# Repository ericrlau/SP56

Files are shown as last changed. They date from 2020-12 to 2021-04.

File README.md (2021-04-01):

# SP56
## A ZMK-Powered BLE Keyboard, Inspired By Lily58 & Sofle

> :warning: **This is a partially tested project.** Do not use to create your own copy unless you are willing to debug the hardware and/or firmware. 
## Flash bootloader
Bootloader is pre-loaded on assembled pcbs. If you source your own BLE module you will need to unlock the module and flash the bootloader using the Nordic nrf command line tool. 
```
$ nrfjprog --recover --log 
```
```
$ nrfjprog -f nrf52 --program firmware/bootloader/COBO_nrf52840_bootloader-0.3.2-184-g64ea299_s140_6.1.1.hex
```

------------------------------------
## Upload Firmware 

- See ZMK docs for instructions on setting up ZMK and custimizing firmware.  
	* https://zmkfirmware.dev/docs/user-setup/
	* https://zmkfirmware.dev/docs/customization 
- Default *.uf2 files are pre-loaded on assembled pcbs. If you sourced and assembled your own pcb, you can file deafult pre-built firmware here: 
	- https://github.com/ericrlau/COBO-zmk-config/releases

## PCB
- Source files for pcb are in this repo. They are split into three kicad projects:
	- SP56: main pcb, left and right combined. 
	- SP56_Bottom: Bottom cover PCB. Left and right use the same part so only one copy is created. 
	- SP56_Plate: Switch plate PCB. This must be 1.2mm pcb to allow Kaihl Choc V1 switches to snap in. Left and right use the same part so only one copy is created. 
	- NOTE: KiCad files are created with nightly KiCad 5.99 builds, they are not compatible with current stable release of KiCad 5.
- Bill of materials [BOM Link](https://raw.githack.com/ericrlau/SP56/working/PCB/SP56/bom/ibom.html)
## Build Guide For PCBA
[Build Guide Link](./Build_Guide.md)

## Images

#### Prototype Build
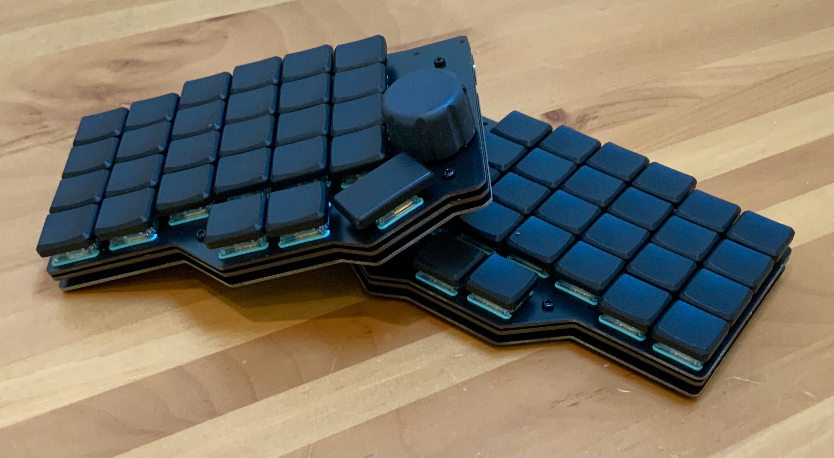
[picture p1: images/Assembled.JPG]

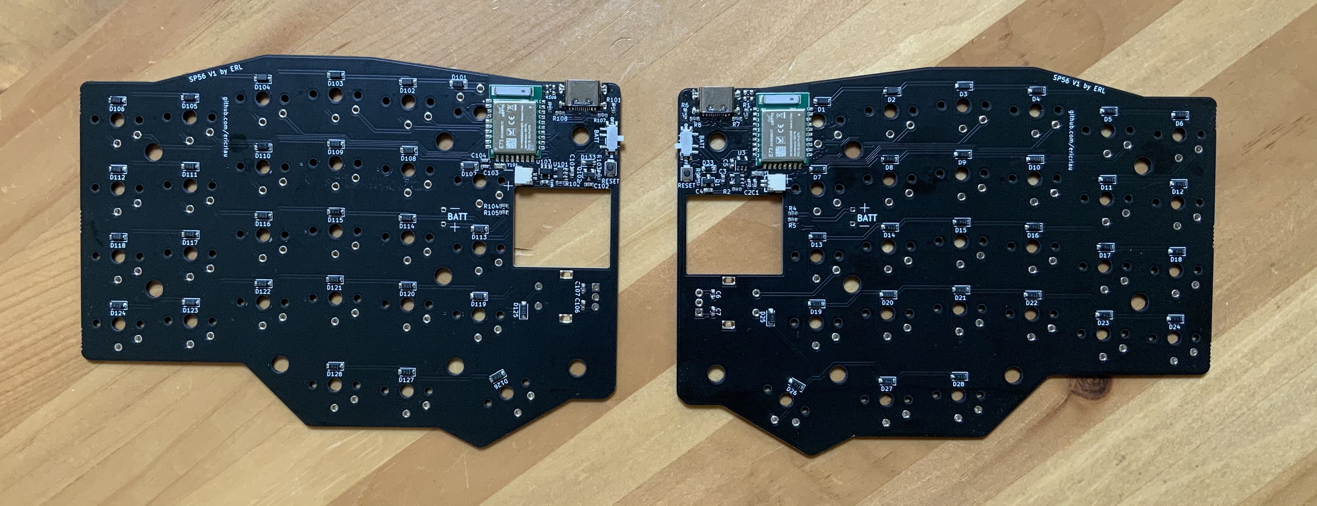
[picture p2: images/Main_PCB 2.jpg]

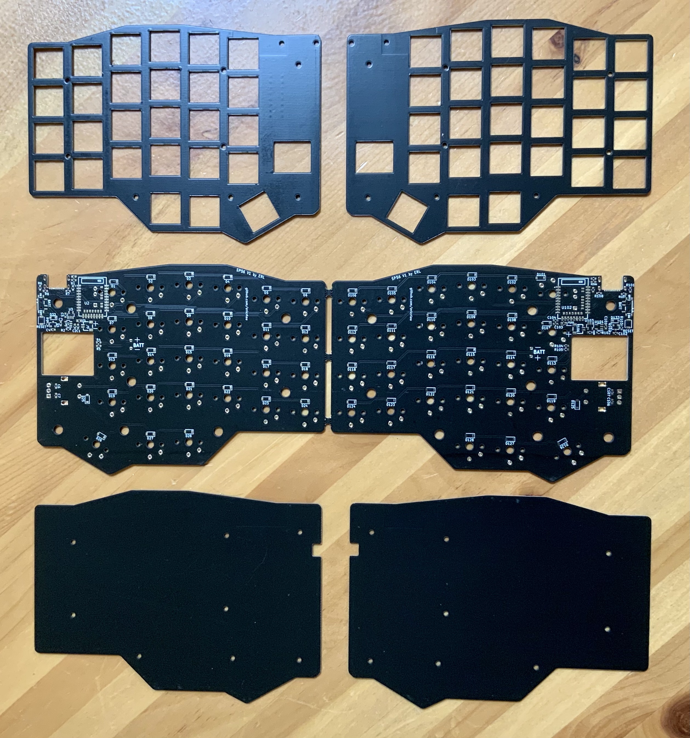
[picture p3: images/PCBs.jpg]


#### Main PCB
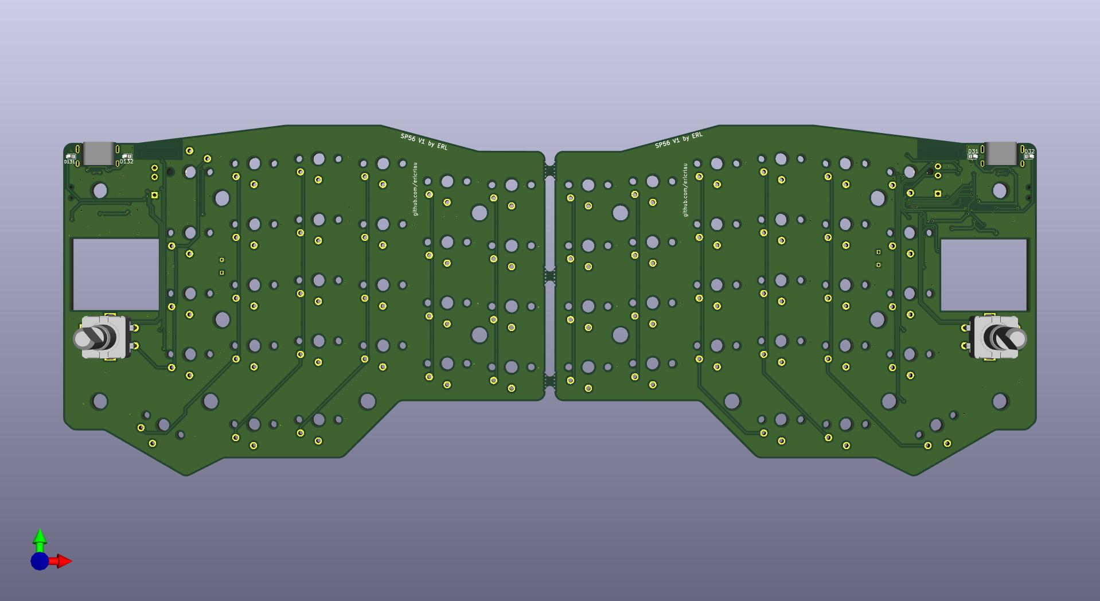
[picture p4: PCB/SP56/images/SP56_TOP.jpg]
Main TOP

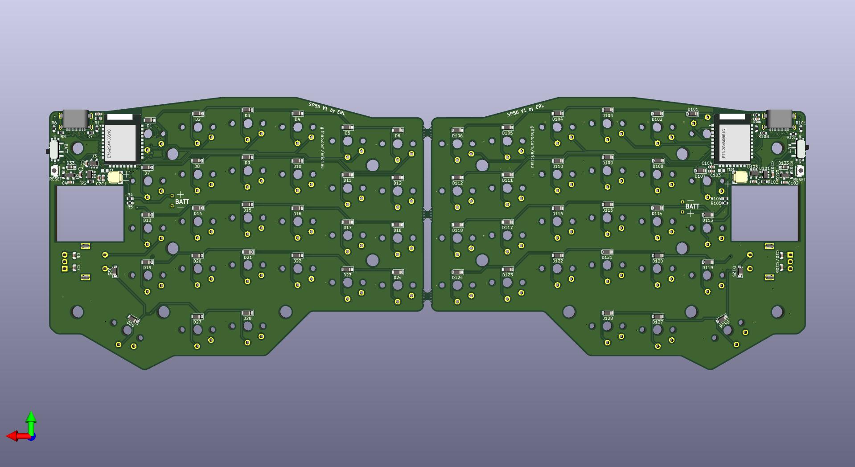
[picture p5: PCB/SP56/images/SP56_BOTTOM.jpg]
Main BOTTOM


#### FR4 Plate
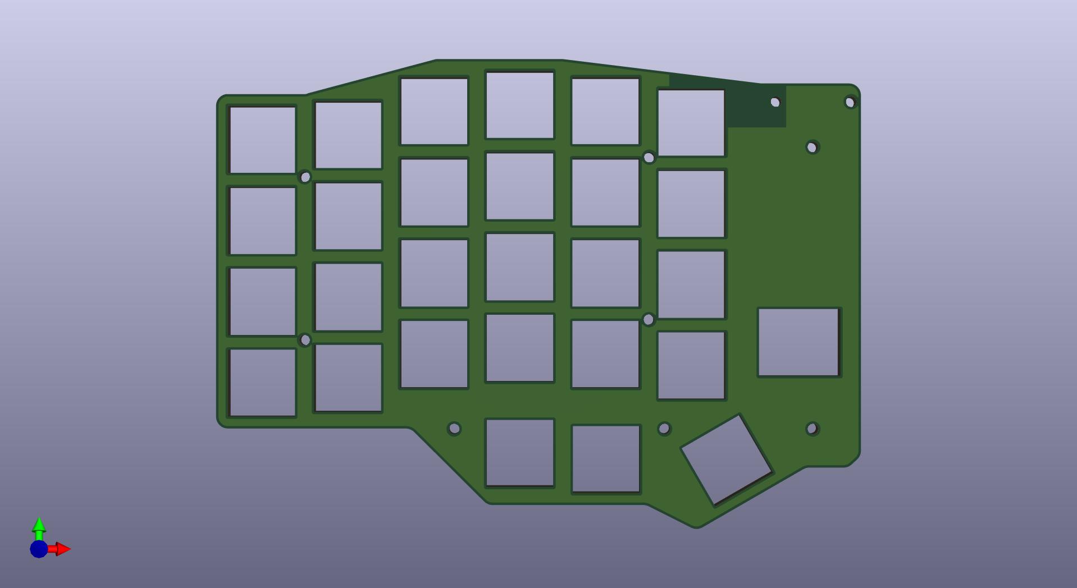
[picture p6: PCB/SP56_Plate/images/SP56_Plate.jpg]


#### Bottom PCB
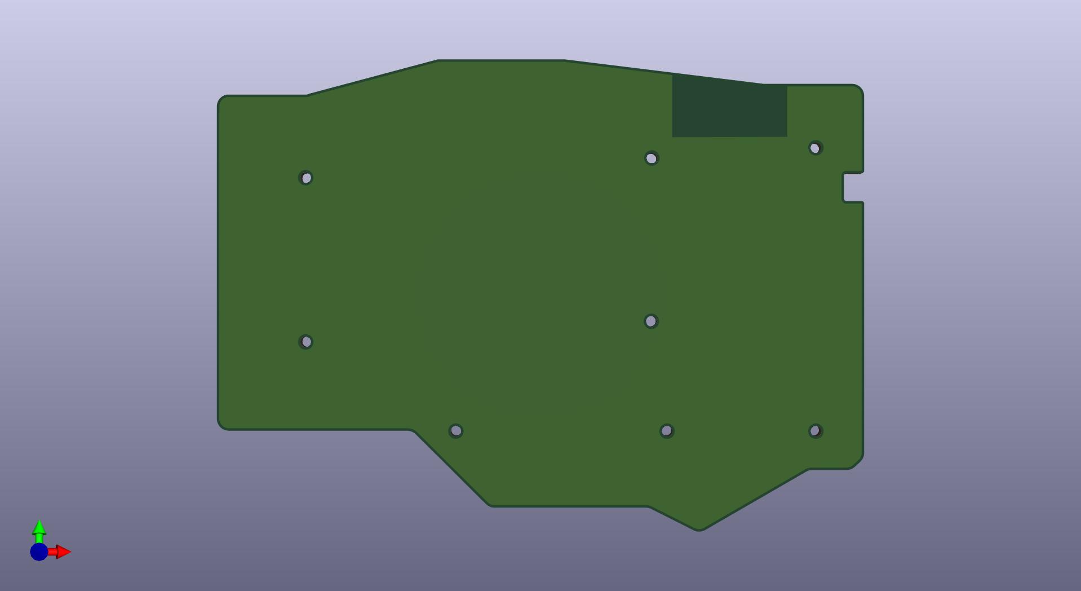
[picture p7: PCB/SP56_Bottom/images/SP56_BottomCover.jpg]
Bottom Cover


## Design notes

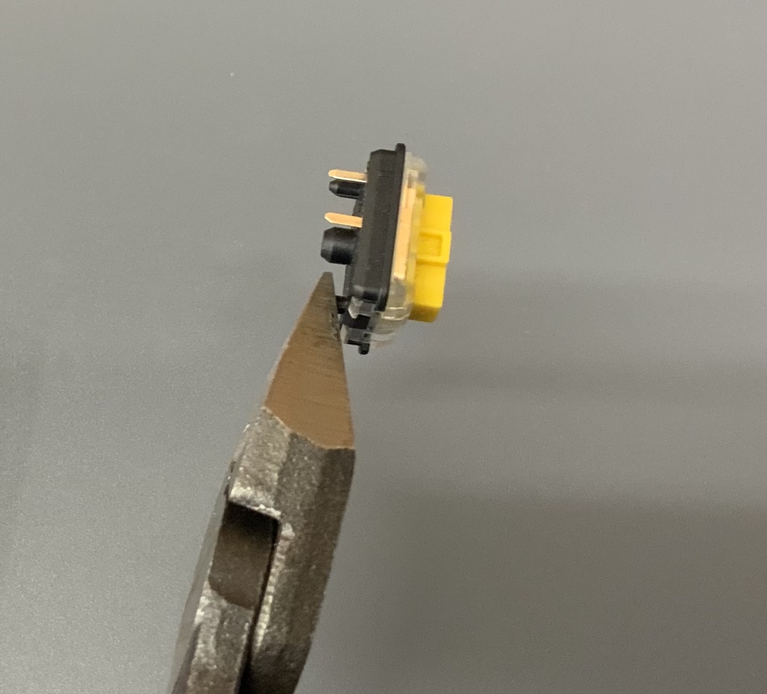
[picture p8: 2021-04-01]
images/Clip.jpg

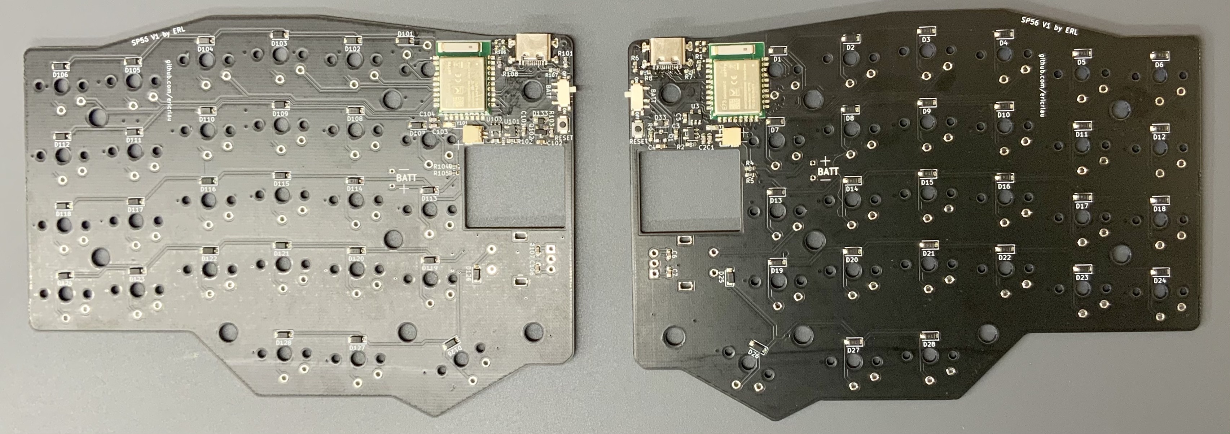
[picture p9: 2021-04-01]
images/Main_PCB.jpg

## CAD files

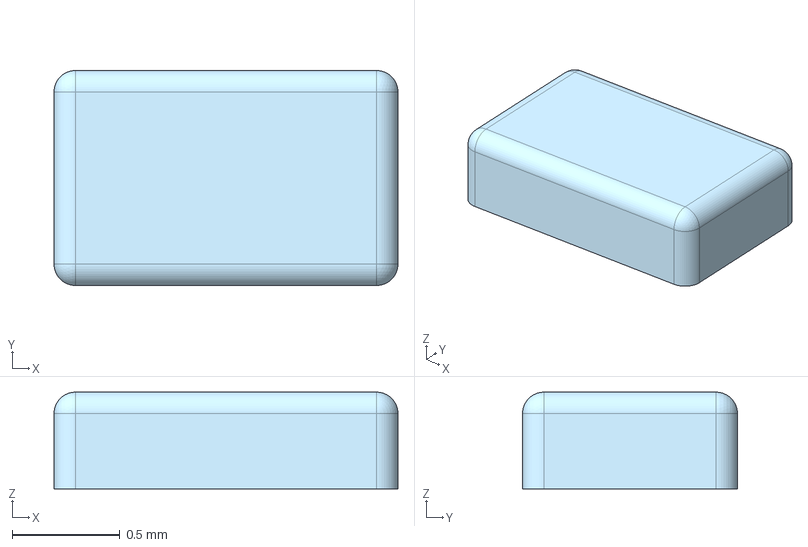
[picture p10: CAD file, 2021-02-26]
PCB/3d/DST1610A.step
1.60 x 1.00 x 0.45 mm

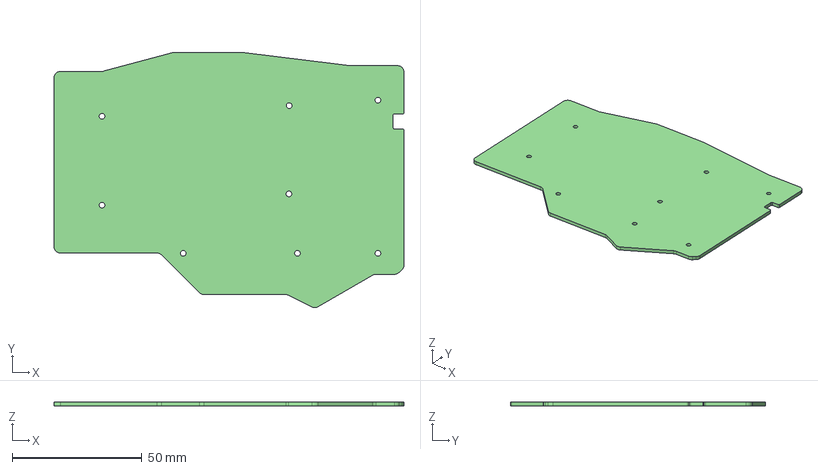
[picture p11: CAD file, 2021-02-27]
PCB/SP56_Bottom/SP56_Bottom.step
134.8 x 98.3 x 1.60 mm

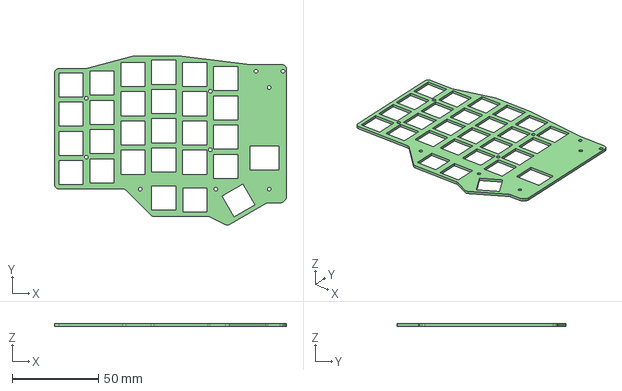
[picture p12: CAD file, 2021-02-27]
PCB/SP56_Plate/SP56_Plate.step
134.8 x 98.3 x 1.60 mm

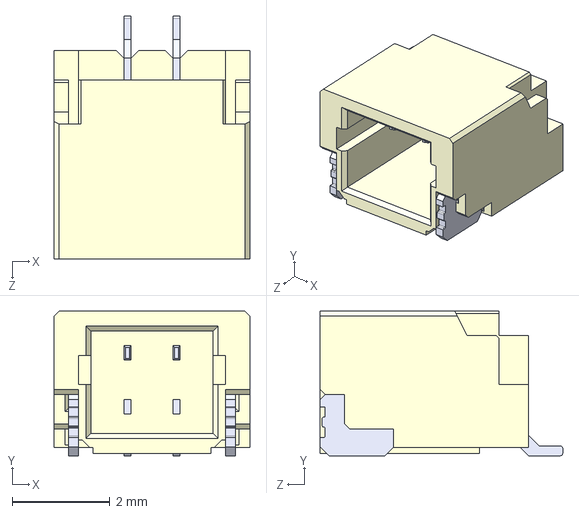
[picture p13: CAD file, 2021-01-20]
PCB/3d/SM02B-SRSS-TB_LF__SN_.step
4.00 x 2.95 x 4.95 mm

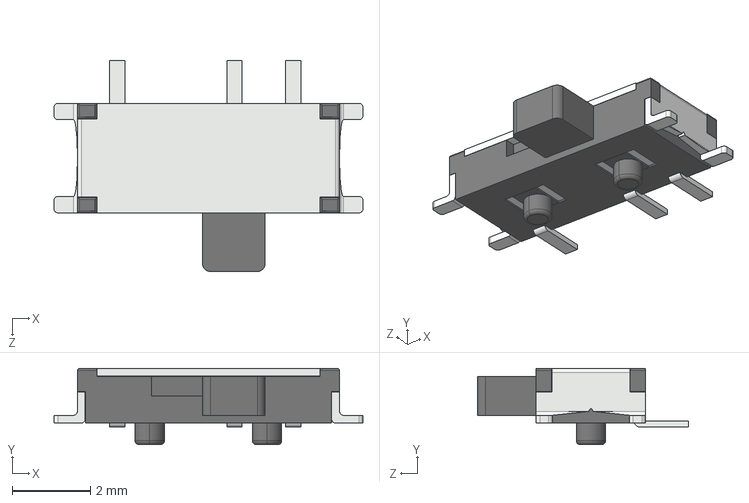
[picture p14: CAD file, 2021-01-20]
PCB/3d/MSK12C02.step
7.90 x 1.95 x 5.39 mm

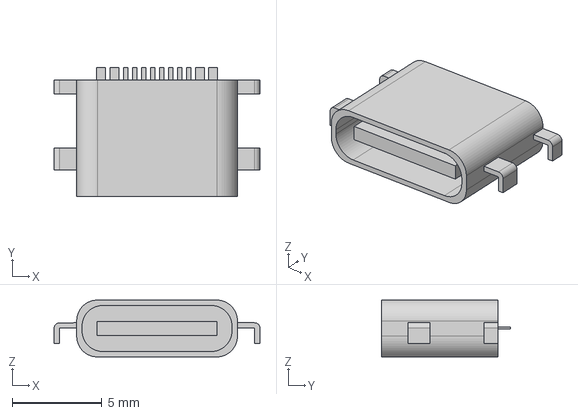
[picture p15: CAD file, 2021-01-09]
PCB/3d/USB-C-C168688.step
11.5 x 7.20 x 3.16 mm

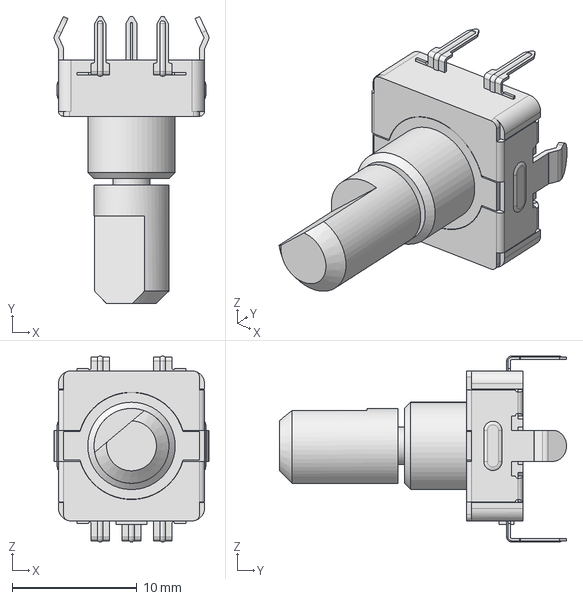
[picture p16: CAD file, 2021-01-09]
PCB/3d/EC11-THT-15F-black.step
12.4 x 23.0 x 14.9 mm

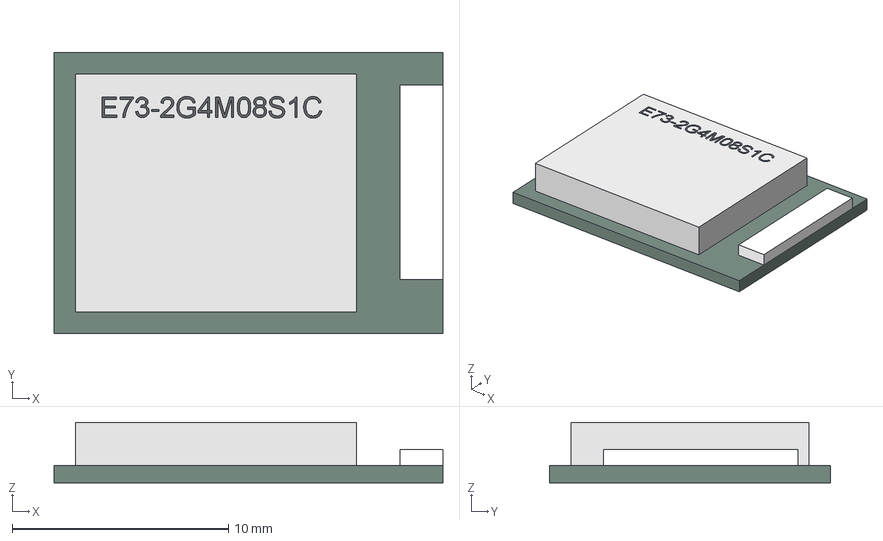
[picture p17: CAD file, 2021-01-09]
PCB/3d/E73-2G4M08S1C.step
18.0 x 13.0 x 2.81 mm

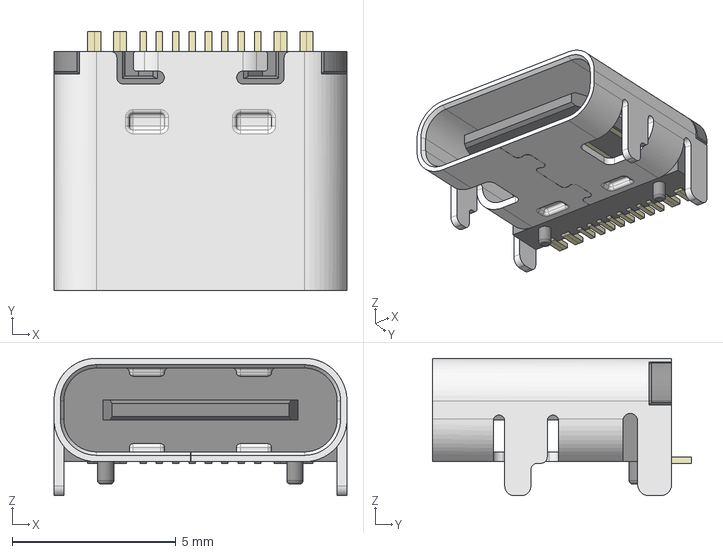
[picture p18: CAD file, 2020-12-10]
PCB/3d/HRO_TYPE-C-31-M-12.step
8.95 x 7.90 x 4.20 mm

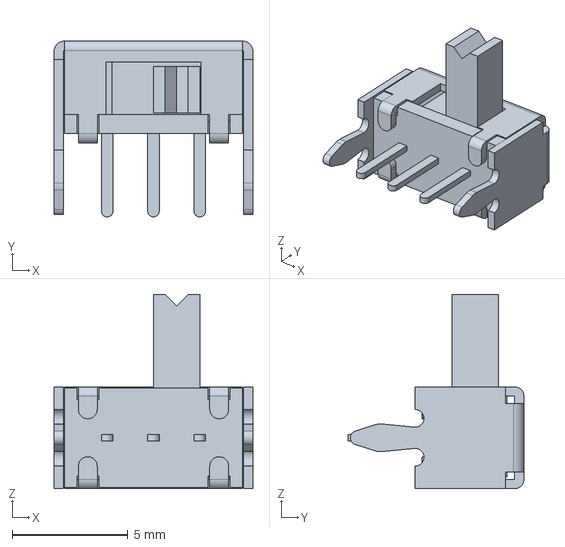
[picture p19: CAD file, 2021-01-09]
PCB/3d/OS102011MA1QN1.stp
8.60 x 7.60 x 8.40 mm

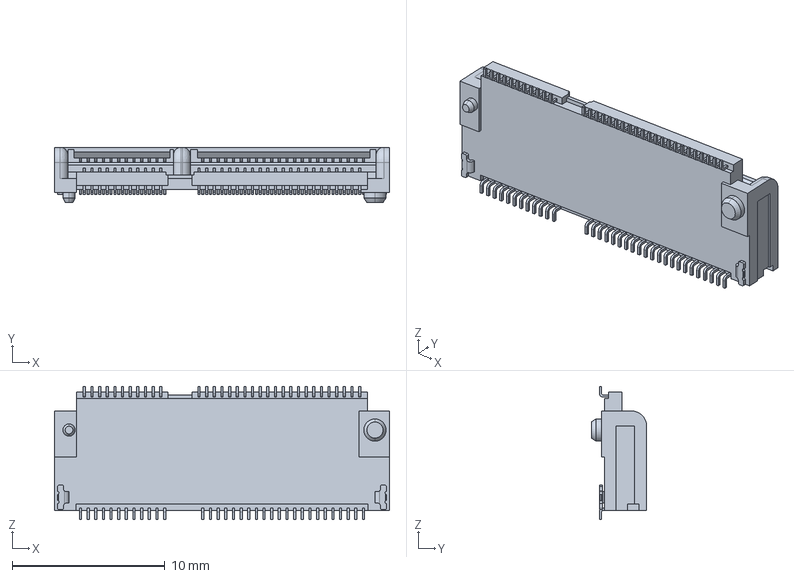
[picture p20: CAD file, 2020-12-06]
PCB/3d/2199119-4.stp
21.9 x 3.62 x 8.70 mm

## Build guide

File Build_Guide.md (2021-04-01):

# SP56
## Build Guide (From PCBA)

> :warning: **This is a partially tested project.** Do not use to create your own copy unless you are willing to debug the hardware and/or firmware. 

---
## What You'll Need
* Kaihl Choc V1 Switches - QTY 54 
* 1U Keycaps - QTY 52
* 1.5U Keycaps - QTY 2
* EC11 Encoders with Knobs - QTY 2
* Li Ion Batteries, less than 20x24x6mm - QTY 2
* Soldering Tools

---

## Unpack From Shipping
* Remove the 8 M2 screws from the top side (switch plate). 
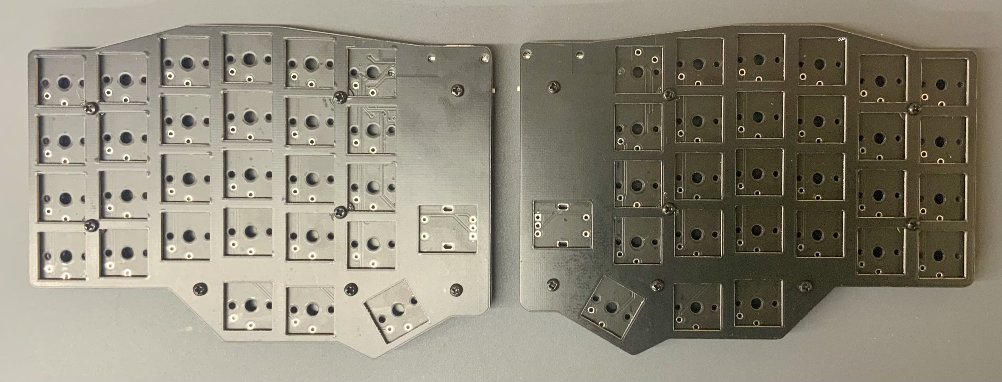
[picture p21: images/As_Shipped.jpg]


* You will see 8 1MM plastic spacers and 8 3MM thick plastic spacers, these are just for shipping and should be removed. 
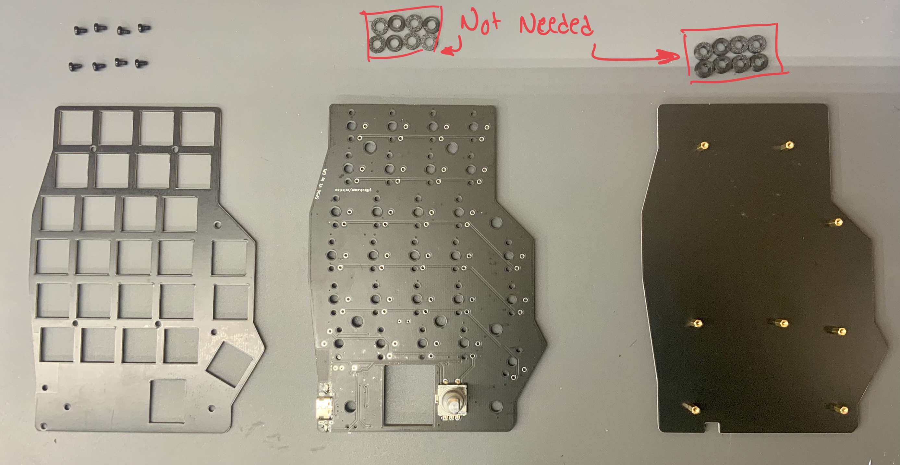
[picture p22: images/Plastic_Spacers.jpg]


## Install Encoder
The SP56 is compatible with EC11 style encoders. You will need 2 encoders and 2 knobs. Install the EC11 style encoder and solder pins. 
* NOTE: If your encoder has plastic locating nubs on the bottom these should be removed to allow encoder to sit flush. 
* Note 2: As of 31 Mar 2021, ZMK firmware does not support encoder functionality on the peripheral (right) side. The right side encoder push switch will be functional but rotating the knob will not. 
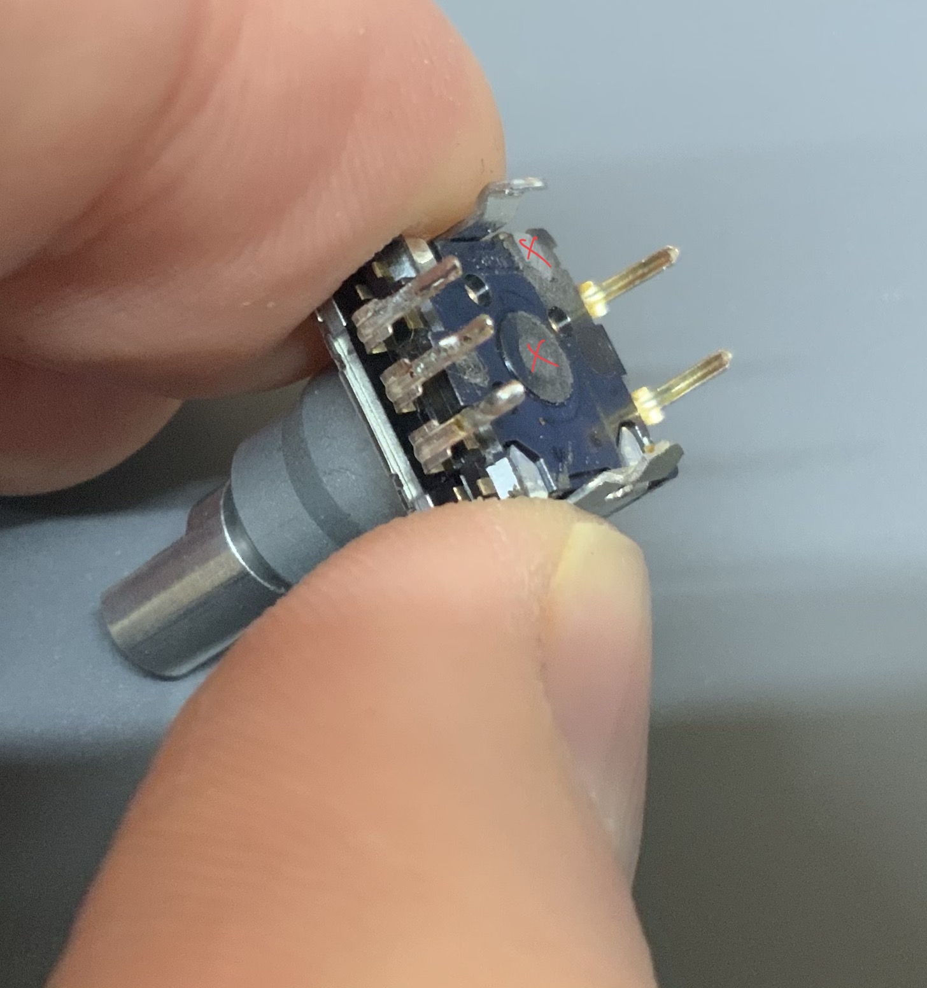
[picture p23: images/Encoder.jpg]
* 

## Plug In and Test via USB
* Before shipping any PCBAs I have flashed default firmware and checked function of all switch positions and encoders; however, it is still a good idea to plug in both PCBs to USB (left board should be connected to USB on your computer, right just needs power so you could use a usb charger) and testing again over USB since it is a lot harder to troubleshoot once the switches are soldered in. Pull up your favorite keyboard testing website and check that left encoder is working and all switch positions work if you short across the two through hole pins with a tweezers. 
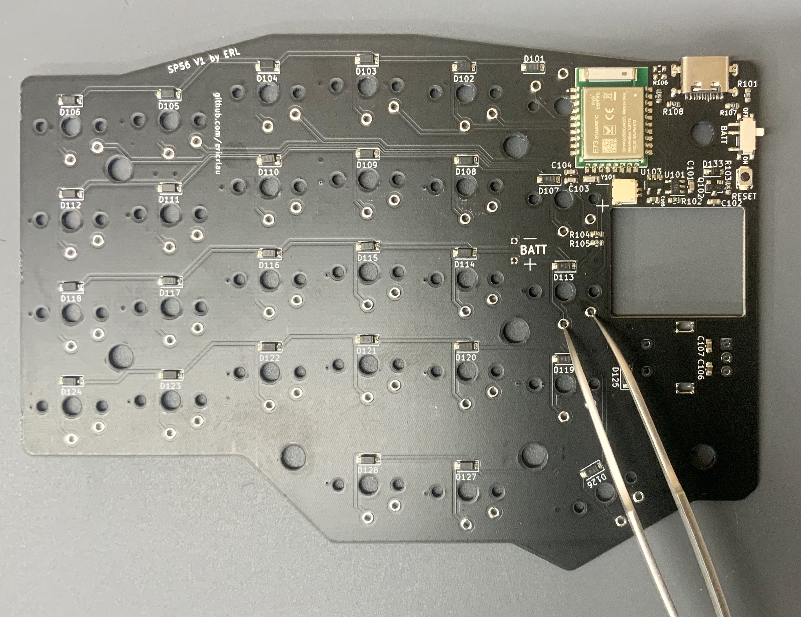
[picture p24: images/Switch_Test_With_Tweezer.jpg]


## Install Switches
The SP56 is compatible with Kaihl Choc V1 switches only. You will need 54 switches in total. 
* Trim 2 switches: On each side, the top inner switch will need to have one of the plastic legs trimmed to a length of 1.6MM or less since the wireless module is directly underneath the switch length. 
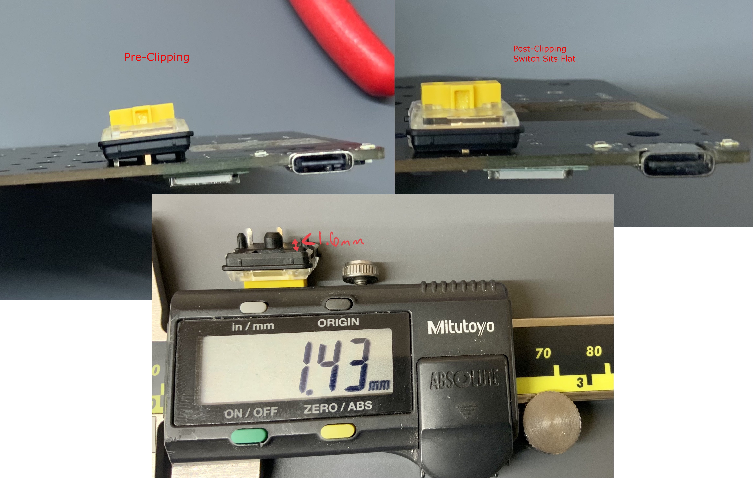
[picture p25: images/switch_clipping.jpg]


* Install First switches into plate: Start by snapping in a few switches to the switch plate to hold the plate while you snap in the remaining switches. 
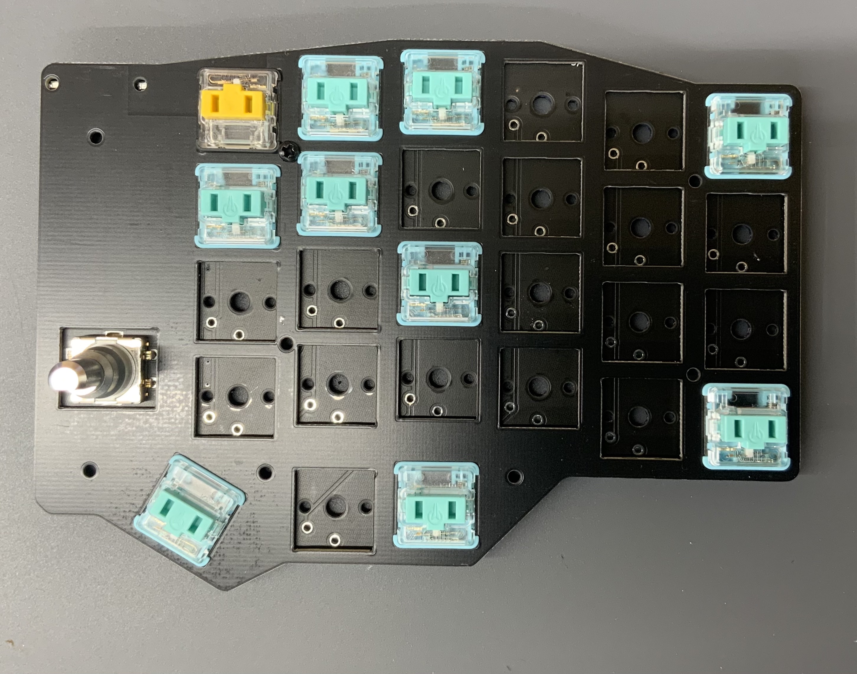
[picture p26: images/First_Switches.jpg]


* Make sure that all switches are snapped into the plate, switches are sitting flat against main pcb and all metal switch legs are in the through-holes on the main PCB. 
* Solder in switches.
* Install keycaps.

## Install Batteries
* If using wirelessly, you will need to install batteries in each side of the board. There is a JST SH connector on the board that you can use, or if you prefer, you can solder to through holes. The battery opening is 24X20MM and is designed around 150mAh batteries from https://tinycircuits.com/collections/batteries/products/lithium-ion-polymer-battery-3-7v-150mah . Other similar size batteries should also work fine. 
* NOTE: there is no standard for battery polarity on batteries that you buy with a connector preinstalled on them. You must confirm that your positive battery wire is connected to the + side of the connector, as marked on silkscreen. 
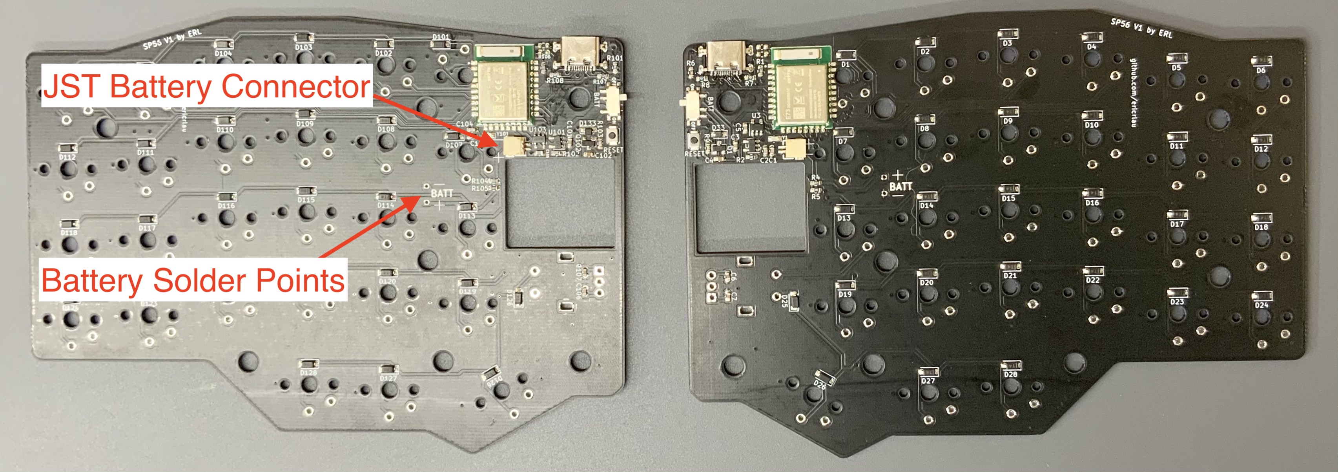
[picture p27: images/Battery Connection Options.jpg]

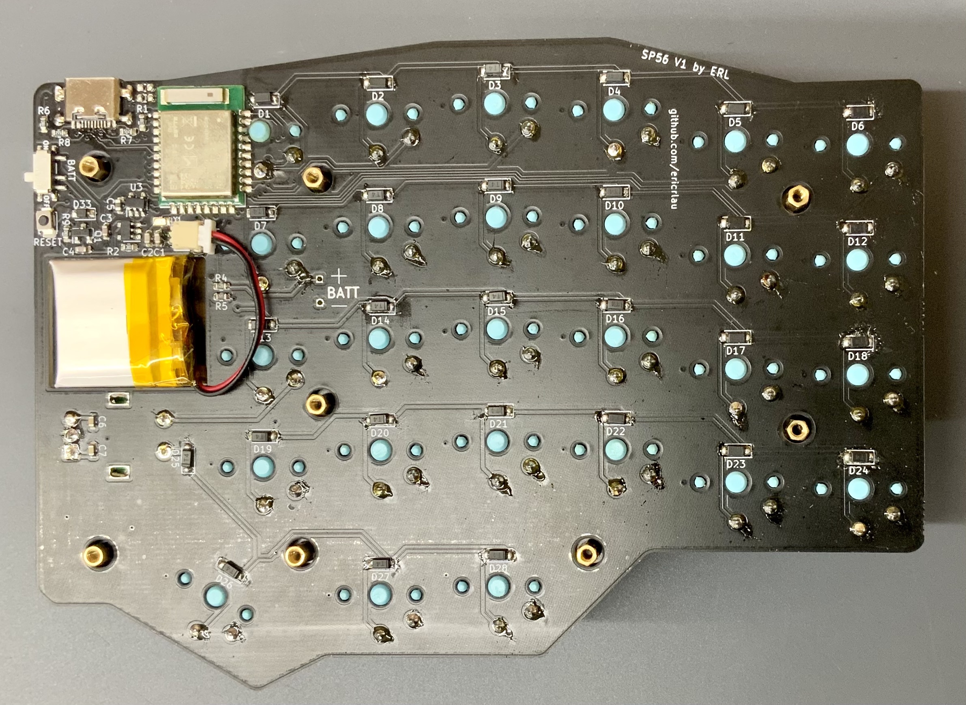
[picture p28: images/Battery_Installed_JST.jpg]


## Install Hex Standoffs And Bottom Cover
* Once all the switches are soldered you can install the hex standoffs and bottom cover again. There is very little clearance for the screw heads on the switch plate side but they should fit. 

## Use
* See ZMK docs for information about firmware customization, flashing, and troubleshooting. 
    * https://zmkfirmware.dev/docs/user-setup/
	* https://zmkfirmware.dev/docs/customization 
* See COBO ZMK Config repo for default firmware
    * https://github.com/ericrlau/COBO-zmk-config
* To put into bootloader mode press the reset button 2 times quickly. You should see a solid blue LED when in bootloader mode. 
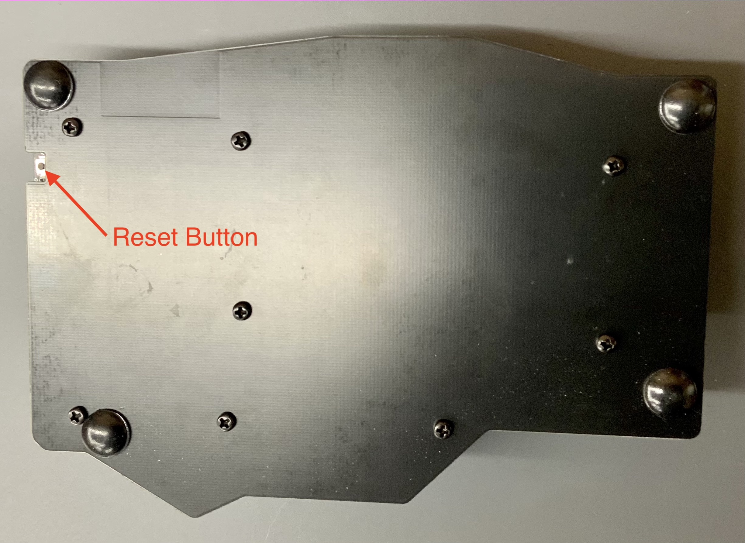
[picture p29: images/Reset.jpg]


* Charging of the Li Ion battery is controlled by an onboard charger. When charging via USB you should see a solid red LED. Once charging is complete the red LED will turn off. 
* There is a power switch on each side. Since the boards are mirrored the off position for the two sides are opposite. Turning the switch off will prevent battery power to the nrf52840 but it will still allow charging and the nrf52840 will still be powered by USB (if plugged in).
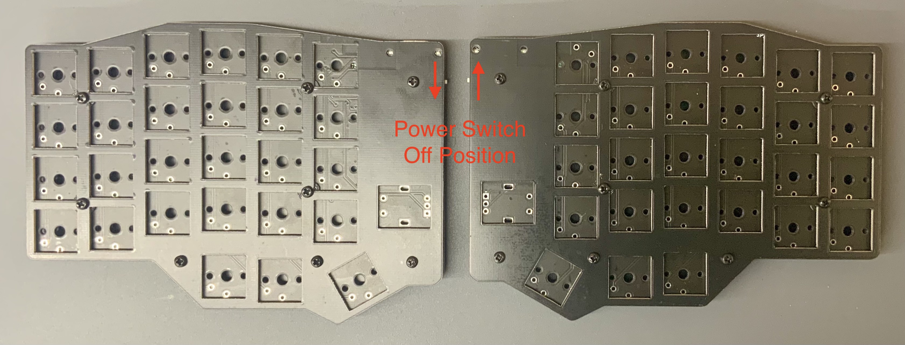
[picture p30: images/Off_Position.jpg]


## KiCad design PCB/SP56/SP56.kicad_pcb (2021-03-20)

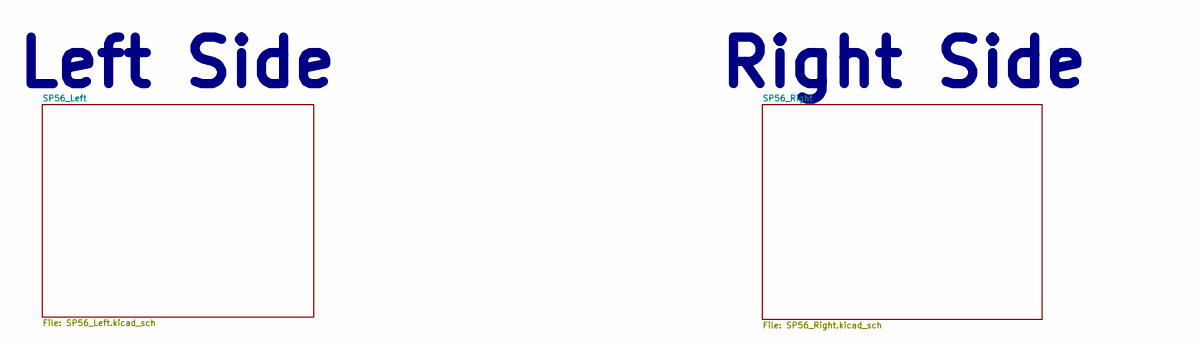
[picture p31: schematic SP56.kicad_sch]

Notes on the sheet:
Left Side
Right Side

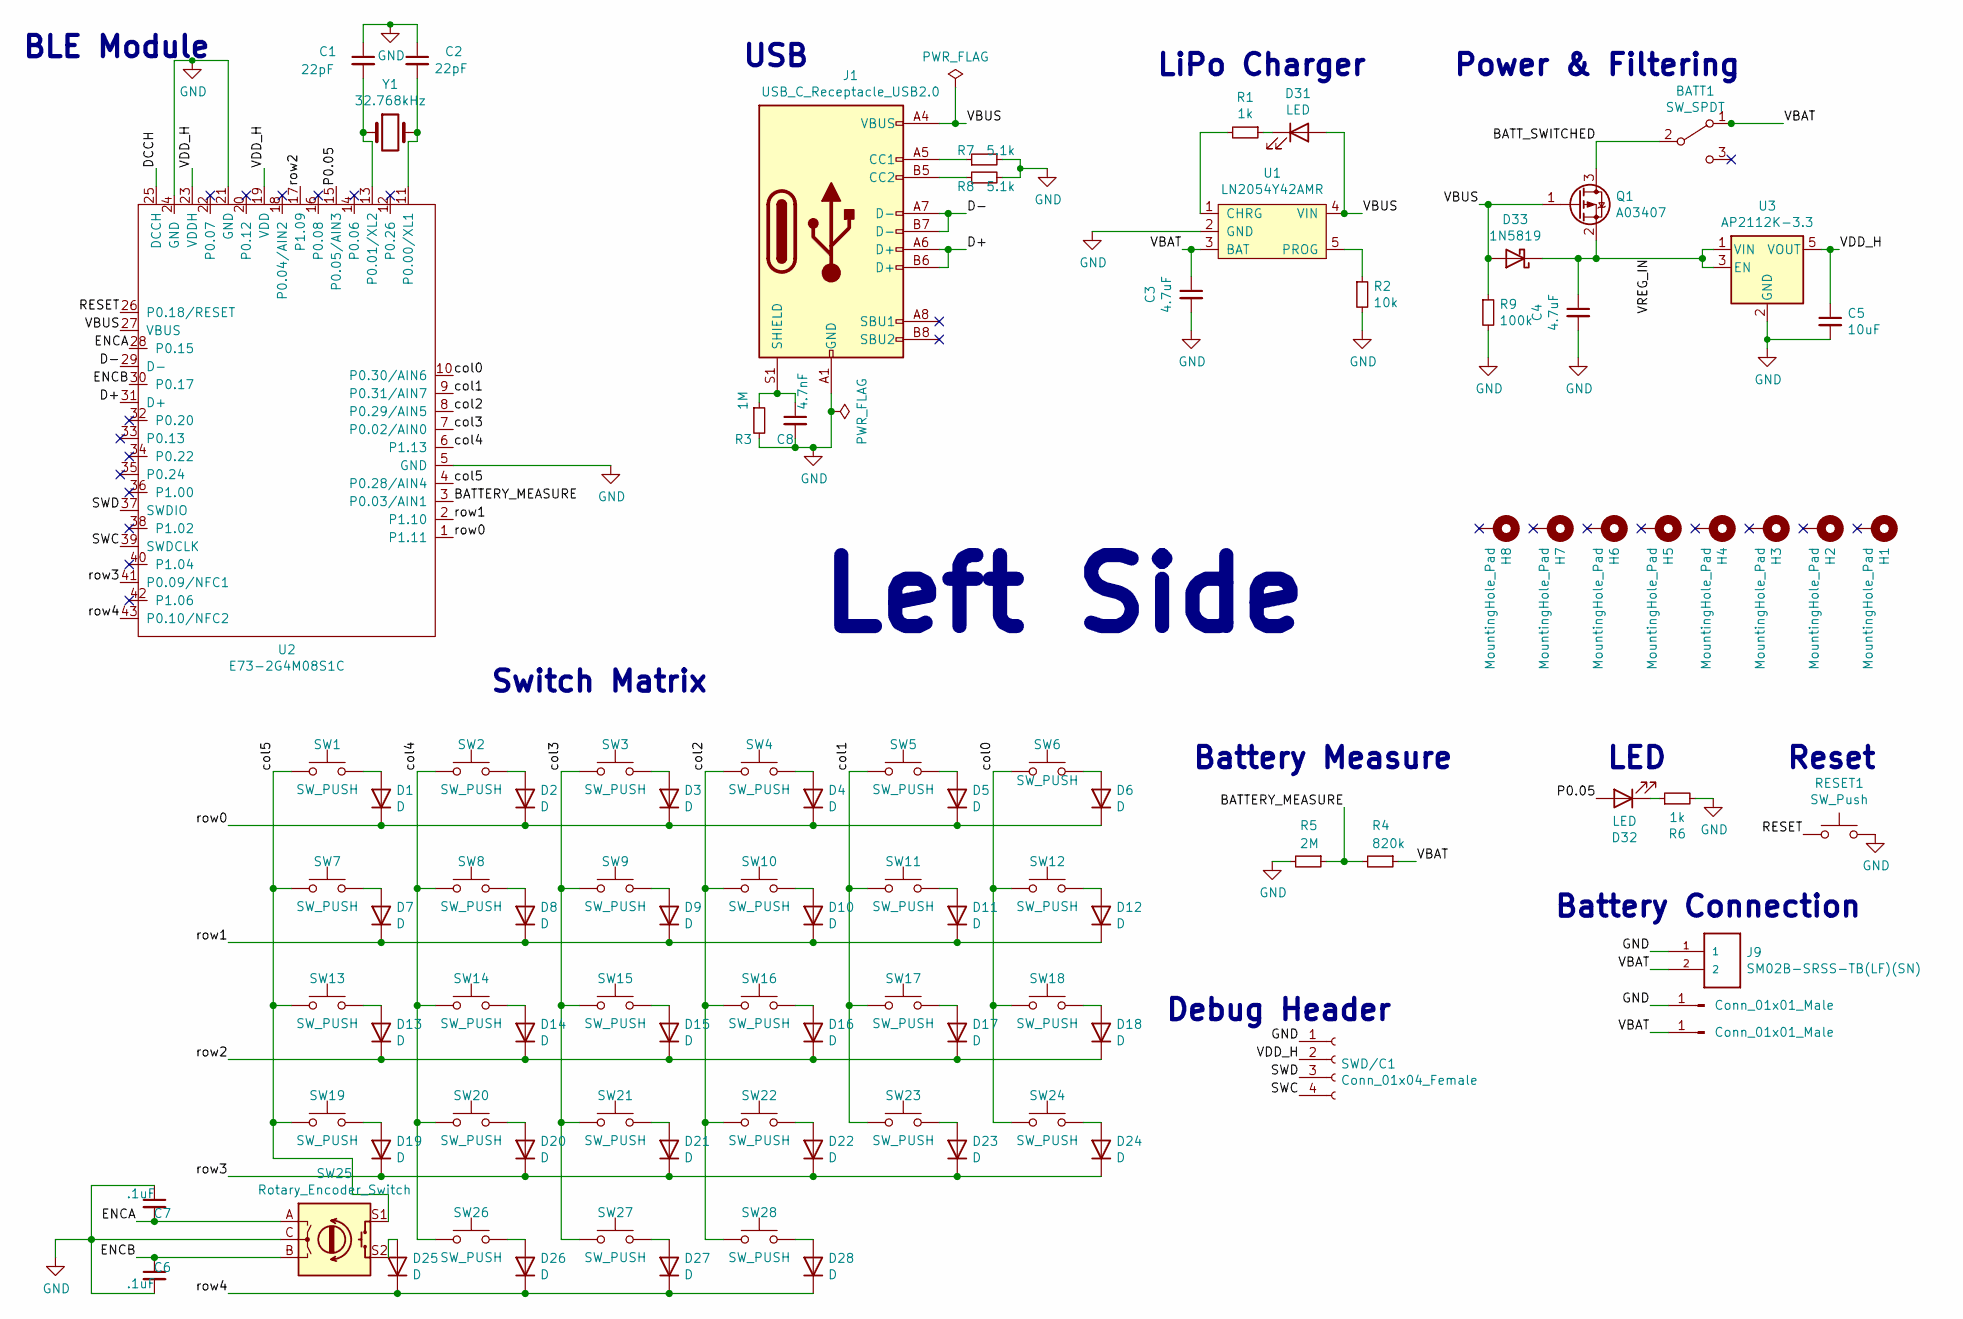
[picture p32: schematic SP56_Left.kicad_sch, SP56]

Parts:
BATT1: SW_SPDT; SW-TH_MSK12C02; LCSC_PN C431540
C1, C2: 22pF; C_0603_1608Metric; LCSC_PN C1653
C3, C4: 4.7uF; C_0603_1608Metric; LCSC_PN C19666
C5: 10uF; C_0603_1608Metric; LCSC_PN C87152
C6, C7: .1uF; C_0603_1608Metric
C8: 4.7nF; C_0603_1608Metric
D1, D2, D3, D4, D5, D6, D7, D8, D9, D10, D11, D12, D13, D14, D15, D16, D17, D18, D19, D20, D21, D22, D23, D24, D25, D26, D27, D28: D; D_SOD-123; LCSC_PN C402213
D31, D32: LED; LED_0603_1608Metric
D33: 1N5819; D_SOD-323_HandSoldering; LCSC_PN C489147
H1, H2, H3, H4, H5, H6, H7, H8: MountingHole_Pad; MountingHole_4.3mm_M4
J1: USB_C_Receptacle_USB2.0; USB-C_C168688; LCSC_PN C168688
J2, J3: Conn_01x01_Male; PinSocket_1x01_P1.27mm_Vertical
J9: SM02B-SRSS-TB(LF)(SN); LCSC_PN C160402
Q1: A03407; SOT-23; LCSC_PN C351408
R1, R6: 1k; R_0603_1608Metric; LCSC_PN C22548
R2: 10k; R_0603_1608Metric; LCSC_PN C98220
R3: 1M; R_0603_1608Metric
R4: 820k; R_0603_1608Metric; LCSC_PN C23252
R5: 2M; R_0603_1608Metric; LCSC_PN C177282
R7, R8: 5.1k; R_0603_1608Metric; LCSC_PN C105580
R9: 100k; R_0603_1608Metric; LCSC_PN C14675
RESET1: SW_Push; SW_SPST_B3U-1000P; LCSC_PN C231329
SW1, SW2, SW3, SW4, SW5, SW6, SW7, SW8, SW9, SW10, SW11, SW12, SW13, SW14, SW15, SW16, SW17, SW18, SW19, SW20, SW21, SW22, SW23, SW24, SW27, SW28: SW_PUSH; KailhLowProfile
SW25: Rotary_Encoder_Switch; RotaryEncoder_Alps_EC11E-Switch_Vertical_H20mm
SW26: SW_PUSH; KailhLowProfile_1.5U
SWD/C1: Conn_01x04_Female; PinHeader_1x04_P2.54mm_Vertical
U1: LN2054Y42AMR; SOT-23-5; LCSC_PN C141406
U2: E73-2G4M08S1C; E73-2G4M08S1C-52840_SMD; LCSC_PN C356849
U3: AP2112K-3.3; SOT-23-5; LCSC_PN C51118
Y1: 32.768kHz; Crystal_SMD_MicroCrystal_CM9V-T1A-2Pin_1.6x1.0mm; LCSC_PN C93230

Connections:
/SP56_Left/BATTERY_MEASURE: R4.2, R5.1, U2.3 (P0.03/AIN1)
/SP56_Left/BATT_SWITCHED: BATT1.2 (B), Q1.3 (D)
/SP56_Left/D+: J1.A6 (D+), J1.B6 (D+), U2.31 (D+)
/SP56_Left/D-: J1.A7 (D-), J1.B7 (D-), U2.29 (D-)
/SP56_Left/DCCH: U2.25 (DCCH)
/SP56_Left/ENCA: C7.2, SW25.A, U2.28 (P0.15)
/SP56_Left/ENCB: C6.1, SW25.B, U2.30 (P0.17)
/SP56_Left/P0.05: D32.2 (A), U2.15 (P0.05/AIN3)
/SP56_Left/RESET: RESET1.1, U2.26 (P0.18/RESET)
/SP56_Left/SWC: SWD/C1.4, U2.39 (SWDCLK)
/SP56_Left/SWD: SWD/C1.3, U2.37 (SWDIO)
/SP56_Left/VBAT: BATT1.1 (A), C3.1, J3.1, J9.2, R4.1, U1.3 (BAT)
/SP56_Left/VBUS: D31.2 (A), D33.2 (A), J1.A4 (VBUS), J1.A9 (VBUS), J1.B4 (VBUS), J1.B9 (VBUS), Q1.1 (G), R9.1, U1.4 (VIN), U2.27 (VBUS)
/SP56_Left/VDD_H: C5.1, SWD/C1.2, U2.19 (VDD), U2.23 (VDDH), U3.5 (VOUT)
/SP56_Left/VREG_IN: C4.1, D33.1 (K), Q1.2 (S), U3.1 (VIN), U3.3 (EN)
/SP56_Left/col0: SW6.1, SW12.1, SW18.1, SW24.1, U2.10 (P0.30/AIN6)
/SP56_Left/col1: SW5.1, SW11.1, SW17.1, SW23.1, U2.9 (P0.31/AIN7)
/SP56_Left/col2: SW4.1, SW10.1, SW16.1, SW22.1, SW28.1, U2.8 (P0.29/AIN5)
/SP56_Left/col3: SW3.1, SW9.1, SW15.1, SW21.1, SW27.1, U2.7 (P0.02/AIN0)
/SP56_Left/col4: SW2.1, SW8.1, SW14.1, SW20.1, SW26.1, U2.6 (P1.13)
/SP56_Left/col5: SW1.1, SW7.1, SW13.1, SW19.1, SW25.S1, U2.4 (P0.28/AIN4)
/SP56_Left/row0: D1.1 (K), D2.1 (K), D3.1 (K), D4.1 (K), D5.1 (K), D6.1 (K), U2.1 (P1.11)
/SP56_Left/row1: D7.1 (K), D8.1 (K), D9.1 (K), D10.1 (K), D11.1 (K), D12.1 (K), U2.2 (P1.10)
/SP56_Left/row2: D13.1 (K), D14.1 (K), D15.1 (K), D16.1 (K), D17.1 (K), D18.1 (K), U2.17 (P1.09)
/SP56_Left/row3: D19.1 (K), D20.1 (K), D21.1 (K), D22.1 (K), D23.1 (K), D24.1 (K), U2.41 (P0.09/NFC1)
/SP56_Left/row4: D25.1 (K), D26.1 (K), D27.1 (K), D28.1 (K), U2.43 (P0.10/NFC2)
GND: C1.1, C2.1, C3.2, C4.2, C5.2, C6.2, C7.1, C8.2, J1.A1 (GND), J1.A12 (GND), J1.B1 (GND), J1.B12 (GND), J2.1, J9.1, R2.2, R3.2, R5.2, R6.2, R7.2, R8.2, R9.2, RESET1.2, SW25.C, SWD/C1.1, U1.2 (GND), U2.5 (GND), U2.21 (GND), U2.24 (GND), U3.2 (GND); also elsewhere on the board
unnamed: C1.2, U2.13 (P0.01/XL2), Y1.1
unnamed: C2.2, U2.11 (P0.00/XL1), Y1.2
unnamed: C8.1, J1.S1 (SHIELD), R3.1
unnamed: D1.2 (A), SW1.2
unnamed: D2.2 (A), SW2.2
unnamed: D3.2 (A), SW3.2
unnamed: D4.2 (A), SW4.2
unnamed: D5.2 (A), SW5.2
unnamed: D6.2 (A), SW6.2
unnamed: D7.2 (A), SW7.2
unnamed: D8.2 (A), SW8.2
unnamed: D9.2 (A), SW9.2
unnamed: D10.2 (A), SW10.2
unnamed: D11.2 (A), SW11.2
unnamed: D12.2 (A), SW12.2
unnamed: D13.2 (A), SW13.2
unnamed: D14.2 (A), SW14.2
unnamed: D15.2 (A), SW15.2
unnamed: D16.2 (A), SW16.2
unnamed: D17.2 (A), SW17.2
unnamed: D18.2 (A), SW18.2
unnamed: D19.2 (A), SW19.2
unnamed: D20.2 (A), SW20.2
unnamed: D21.2 (A), SW21.2
unnamed: D22.2 (A), SW22.2
unnamed: D23.2 (A), SW23.2
unnamed: D24.2 (A), SW24.2
unnamed: D25.2 (A), SW25.S2
unnamed: D26.2 (A), SW26.2
unnamed: D27.2 (A), SW27.2
unnamed: D28.2 (A), SW28.2
unnamed: D31.1 (K), R1.1
unnamed: D32.1 (K), R6.1
unnamed: J1.A5 (CC1), R7.1
unnamed: J1.B5 (CC2), R8.1
unnamed: R1.2, U1.1 (CHRG)
unnamed: R2.1, U1.5 (PROG)

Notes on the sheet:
BLE Module
Switch Matrix
USB
Left Side
LiPo Charger
Debug Header
Battery Measure
Power & Filtering
Battery Connection
LED
Reset

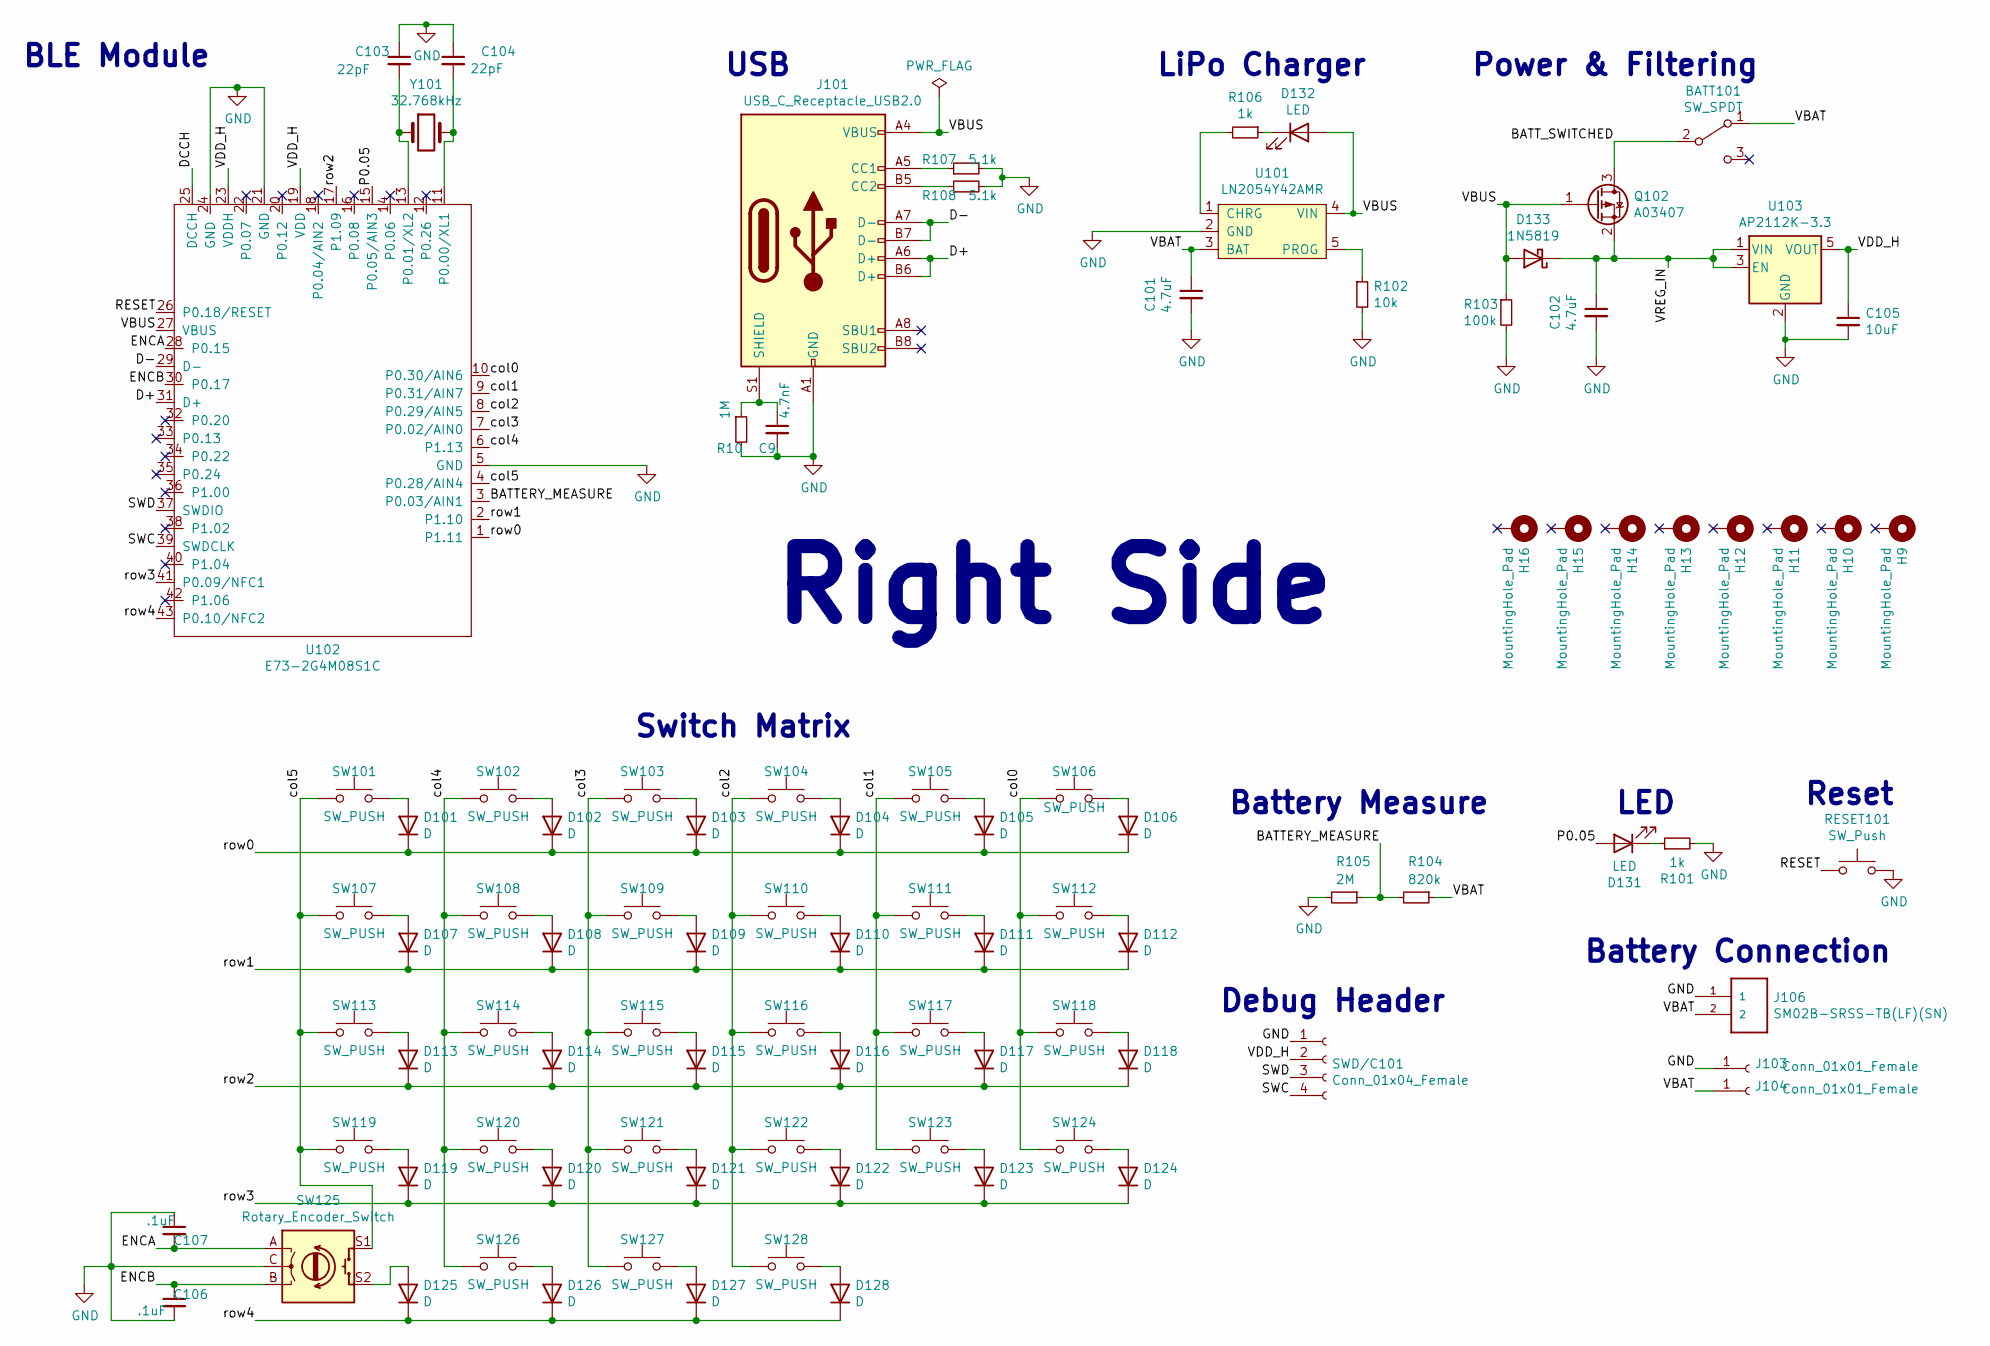
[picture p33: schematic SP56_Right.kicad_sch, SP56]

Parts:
BATT101: SW_SPDT; SW-TH_MSK12C02; LCSC_PN C431540
C9: 4.7nF; C_0603_1608Metric
C101, C102: 4.7uF; C_0603_1608Metric; LCSC_PN C19666
C103, C104: 22pF; C_0603_1608Metric; LCSC_PN C1653
C105: 10uF; C_0603_1608Metric; LCSC_PN C326057
C106, C107: .1uF; C_0603_1608Metric
D101, D102, D103, D104, D105, D106, D107, D108, D109, D110, D111, D112, D113, D114, D115, D116, D117, D118, D119, D120, D121, D122, D123, D124, D125, D126, D127, D128: D; D_SOD-123; LCSC_PN C402213
D131, D132: LED; LED_0603_1608Metric
D133: 1N5819; D_SOD-323_HandSoldering; LCSC_PN C489147
H9, H10, H11, H12, H13, H14, H15, H16: MountingHole_Pad; MountingHole_4.3mm_M4
J101: USB_C_Receptacle_USB2.0; USB-C_C168688; LCSC_PN C168688
J103, J104: Conn_01x01_Female; PinSocket_1x01_P1.27mm_Vertical
J106: SM02B-SRSS-TB(LF)(SN); LCSC_PN C160402
Q102: A03407; SOT-23; LCSC_PN C351408
R10: 1M; R_0603_1608Metric
R101, R106: 1k; R_0603_1608Metric; LCSC_PN C22548
R102: 10k; R_0603_1608Metric; LCSC_PN C98220
R103: 100k; R_0603_1608Metric; LCSC_PN C14675
R104: 820k; R_0603_1608Metric; LCSC_PN C23252
R105: 2M; R_0603_1608Metric; LCSC_PN C177282
R107, R108: 5.1k; R_0603_1608Metric; LCSC_PN C105580
RESET101: SW_Push; SW_SPST_B3U-1000P; LCSC_PN C231329
SW101, SW102, SW103, SW104, SW105, SW106, SW107, SW108, SW109, SW110, SW111, SW112, SW113, SW114, SW115, SW116, SW117, SW118, SW119, SW120, SW121, SW122, SW123, SW124, SW127, SW128: SW_PUSH; KailhLowProfile
SW125: Rotary_Encoder_Switch; RotaryEncoder_Alps_EC11E-Switch_Vertical_H20mm
SW126: SW_PUSH; KailhLowProfile_1.5U
SWD/C101: Conn_01x04_Female; PinHeader_1x04_P2.54mm_Vertical
U101: LN2054Y42AMR; SOT-23-5; LCSC_PN C141406
U102: E73-2G4M08S1C; E73-2G4M08S1C-52840_SMD; LCSC_PN C356849
U103: AP2112K-3.3; SOT-23-5; LCSC_PN C51118
Y101: 32.768kHz; Crystal_SMD_MicroCrystal_CM9V-T1A-2Pin_1.6x1.0mm; LCSC_PN C93230

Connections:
/SP56_Right/BATTERY_MEASURE: R104.2, R105.1, U102.3 (P0.03/AIN1)
/SP56_Right/BATT_SWITCHED: BATT101.2 (B), Q102.3 (D)
/SP56_Right/D+: J101.A6 (D+), J101.B6 (D+), U102.31 (D+)
/SP56_Right/D-: J101.A7 (D-), J101.B7 (D-), U102.29 (D-)
/SP56_Right/DCCH: U102.25 (DCCH)
/SP56_Right/ENCA: C107.2, SW125.A, U102.28 (P0.15)
/SP56_Right/ENCB: C106.1, SW125.B, U102.30 (P0.17)
/SP56_Right/P0.05: D131.2 (A), U102.15 (P0.05/AIN3)
/SP56_Right/RESET: RESET101.1, U102.26 (P0.18/RESET)
/SP56_Right/SWC: SWD/C101.4, U102.39 (SWDCLK)
/SP56_Right/SWD: SWD/C101.3, U102.37 (SWDIO)
/SP56_Right/VBAT: BATT101.1 (A), C101.1, J104.1, J106.2, R104.1, U101.3 (BAT)
/SP56_Right/VBUS: D132.2 (A), D133.2 (A), J101.A4 (VBUS), J101.A9 (VBUS), J101.B4 (VBUS), J101.B9 (VBUS), Q102.1 (G), R103.1, U101.4 (VIN), U102.27 (VBUS)
/SP56_Right/VDD_H: C105.1, SWD/C101.2, U102.19 (VDD), U102.23 (VDDH), U103.5 (VOUT)
/SP56_Right/VREG_IN: C102.1, D133.1 (K), Q102.2 (S), U103.1 (VIN), U103.3 (EN)
/SP56_Right/col0: SW106.1, SW112.1, SW118.1, SW124.1, U102.10 (P0.30/AIN6)
/SP56_Right/col1: SW105.1, SW111.1, SW117.1, SW123.1, U102.9 (P0.31/AIN7)
/SP56_Right/col2: SW104.1, SW110.1, SW116.1, SW122.1, SW128.1, U102.8 (P0.29/AIN5)
/SP56_Right/col3: SW103.1, SW109.1, SW115.1, SW121.1, SW127.1, U102.7 (P0.02/AIN0)
/SP56_Right/col4: SW102.1, SW108.1, SW114.1, SW120.1, SW126.1, U102.6 (P1.13)
/SP56_Right/col5: SW101.1, SW107.1, SW113.1, SW119.1, SW125.S1, U102.4 (P0.28/AIN4)
/SP56_Right/row0: D101.1 (K), D102.1 (K), D103.1 (K), D104.1 (K), D105.1 (K), D106.1 (K), U102.1 (P1.11)
/SP56_Right/row1: D107.1 (K), D108.1 (K), D109.1 (K), D110.1 (K), D111.1 (K), D112.1 (K), U102.2 (P1.10)
/SP56_Right/row2: D113.1 (K), D114.1 (K), D115.1 (K), D116.1 (K), D117.1 (K), D118.1 (K), U102.17 (P1.09)
/SP56_Right/row3: D119.1 (K), D120.1 (K), D121.1 (K), D122.1 (K), D123.1 (K), D124.1 (K), U102.41 (P0.09/NFC1)
/SP56_Right/row4: D125.1 (K), D126.1 (K), D127.1 (K), D128.1 (K), U102.43 (P0.10/NFC2)
GND: C9.2, C101.2, C102.2, C103.1, C104.1, C105.2, C106.2, C107.1, J101.A1 (GND), J101.A12 (GND), J101.B1 (GND), J101.B12 (GND), J103.1, J106.1, R10.2, R101.2, R102.2, R103.2, R105.2, R107.2, R108.2, RESET101.2, SW125.C, SWD/C101.1, U101.2 (GND), U102.5 (GND), U102.21 (GND), U102.24 (GND), U103.2 (GND); also elsewhere on the board
unnamed: C9.1, J101.S1 (SHIELD), R10.1
unnamed: C103.2, U102.13 (P0.01/XL2), Y101.1
unnamed: C104.2, U102.11 (P0.00/XL1), Y101.2
unnamed: D101.2 (A), SW101.2
unnamed: D102.2 (A), SW102.2
unnamed: D103.2 (A), SW103.2
unnamed: D104.2 (A), SW104.2
unnamed: D105.2 (A), SW105.2
unnamed: D106.2 (A), SW106.2
unnamed: D107.2 (A), SW107.2
unnamed: D108.2 (A), SW108.2
unnamed: D109.2 (A), SW109.2
unnamed: D110.2 (A), SW110.2
unnamed: D111.2 (A), SW111.2
unnamed: D112.2 (A), SW112.2
unnamed: D113.2 (A), SW113.2
unnamed: D114.2 (A), SW114.2
unnamed: D115.2 (A), SW115.2
unnamed: D116.2 (A), SW116.2
unnamed: D117.2 (A), SW117.2
unnamed: D118.2 (A), SW118.2
unnamed: D119.2 (A), SW119.2
unnamed: D120.2 (A), SW120.2
unnamed: D121.2 (A), SW121.2
unnamed: D122.2 (A), SW122.2
unnamed: D123.2 (A), SW123.2
unnamed: D124.2 (A), SW124.2
unnamed: D125.2 (A), SW125.S2
unnamed: D126.2 (A), SW126.2
unnamed: D127.2 (A), SW127.2
unnamed: D128.2 (A), SW128.2
unnamed: D131.1 (K), R101.1
unnamed: D132.1 (K), R106.1
unnamed: J101.A5 (CC1), R107.1
unnamed: J101.B5 (CC2), R108.1
unnamed: R102.1, U101.5 (PROG)
unnamed: R106.2, U101.1 (CHRG)

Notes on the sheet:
BLE Module
Switch Matrix
USB
Right Side
LiPo Charger
Debug Header
Battery Measure
Power & Filtering
Battery Connection
LED
Reset

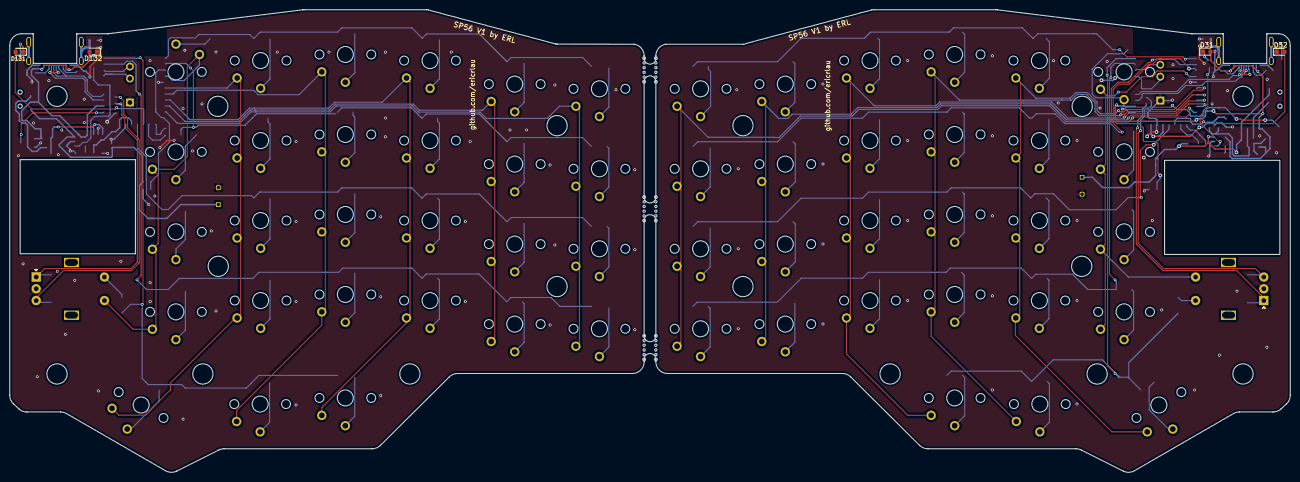
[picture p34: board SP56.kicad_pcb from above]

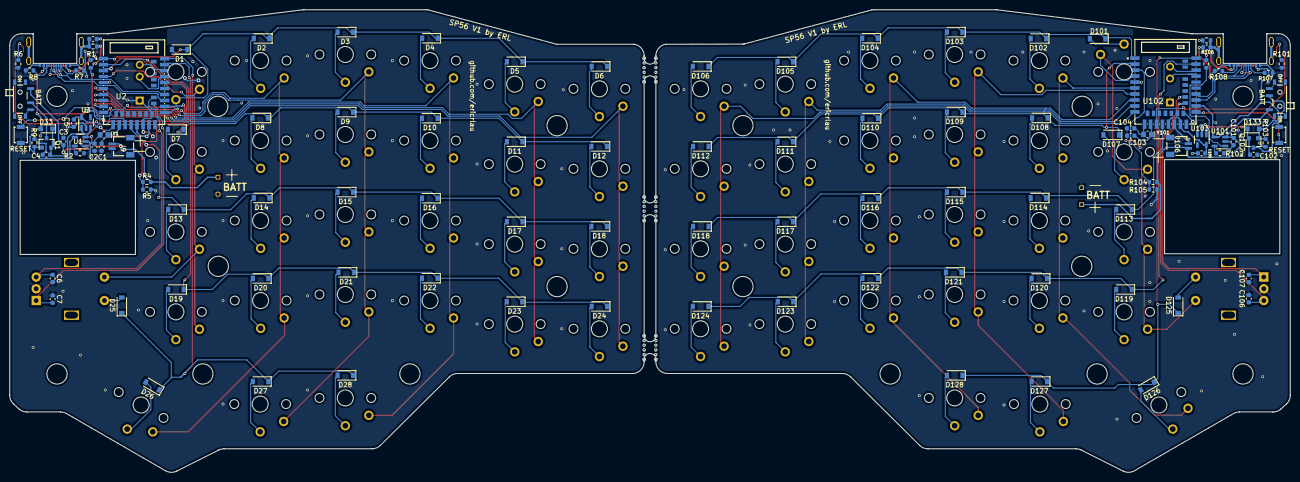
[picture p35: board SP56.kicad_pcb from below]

Board: 2 copper layers, 272.1 x 98.3 mm, 192 parts (117 on the bottom side), 125 nets.

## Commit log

2020-12-08 initial layout
    [BlueSof.kicad_pcb, BlueSof.sch]
2020-12-09 before 2nd side
    [BlueSof.kicad_pcb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]
2020-12-09 EOD, layout on side 2 done, not routed
    [BlueSof.kicad_pcb, BlueSof.sch]
2020-12-09 autoroute done, still needs cleanup
    [BlueSof.kicad_pcb]
2020-12-10 making progress on autoroute cleanup
    [BlueSof.kicad_pcb, BlueSof.sch]
2020-12-13 ordered first boards
    [BlueSof-B_Cu.gbl, BlueSof-B_Mask.gbs, BlueSof-B_SilkS.gbo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]
2020-12-14 R2 version with minor fixes
    [BlueSof-B_Cu.gbl, BlueSof-B_Mask.gbs, BlueSof-B_SilkS.gbo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]
2020-12-28 update switch footprint to reduce center hole size
2021-01-07 update to kicad6
    [2199119-4.stp, BlueSof.kicad_pcb, BlueSof.kicad_sch]
2021-01-07 first commit, side 1
    [BlueSof.kicad_pcb, BlueSof.kicad_sch]
2021-01-09 getting close to layout on side 1
    [BlueSof.kicad_pcb, BlueSof.kicad_sch, E73-2G4M08S1C.step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]
2021-01-20 initial route done, side 1
    [BlueSof.kicad_pcb, BlueSof.kicad_sch, MSK12C02.step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]
2021-01-23 right side draft done
    [BlueSof-B_Cu.gbl, BlueSof-B_Mask.gbs, BlueSof-B_SilkS.gbo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]
2021-01-25 ordered left side from jlc
    [BlueSof-B_Cu.gbl, BlueSof-B_Mask.gbs, BlueSof-B_Silkscreen.gbo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]
2021-02-22 minor updates for SMD assembly
    [BlueSof-B_Cu.gbl, BlueSof-B_Mask.gbs, BlueSof-B_Silkscreen.gbo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]
2021-02-23 working towards next order
    [BlueSof.kicad_pcb, BlueSof.kicad_sch]
2021-02-26 layout almost done
    [DST1610A.step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]
2021-02-27 ready for jlc quote
    [BOM_SP56_R1.xlsx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]
2021-03-07 order SP56 R1 from JLC
    [BOM_SP56_R1.xlsx, POS_SP56_R1.xlsx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]
2021-03-20 clean up old files
    [BOM_SP56_R1.xlsx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]
2021-03-20 readme updates and minor cleanup
    [SP56.kicad_pcb]
2021-03-21 cleanup and readme
    [BlueSof-B_Cu.gbl, BlueSof-B_Mask.gbs, BlueSof-B_Silkscreen.gbo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]
